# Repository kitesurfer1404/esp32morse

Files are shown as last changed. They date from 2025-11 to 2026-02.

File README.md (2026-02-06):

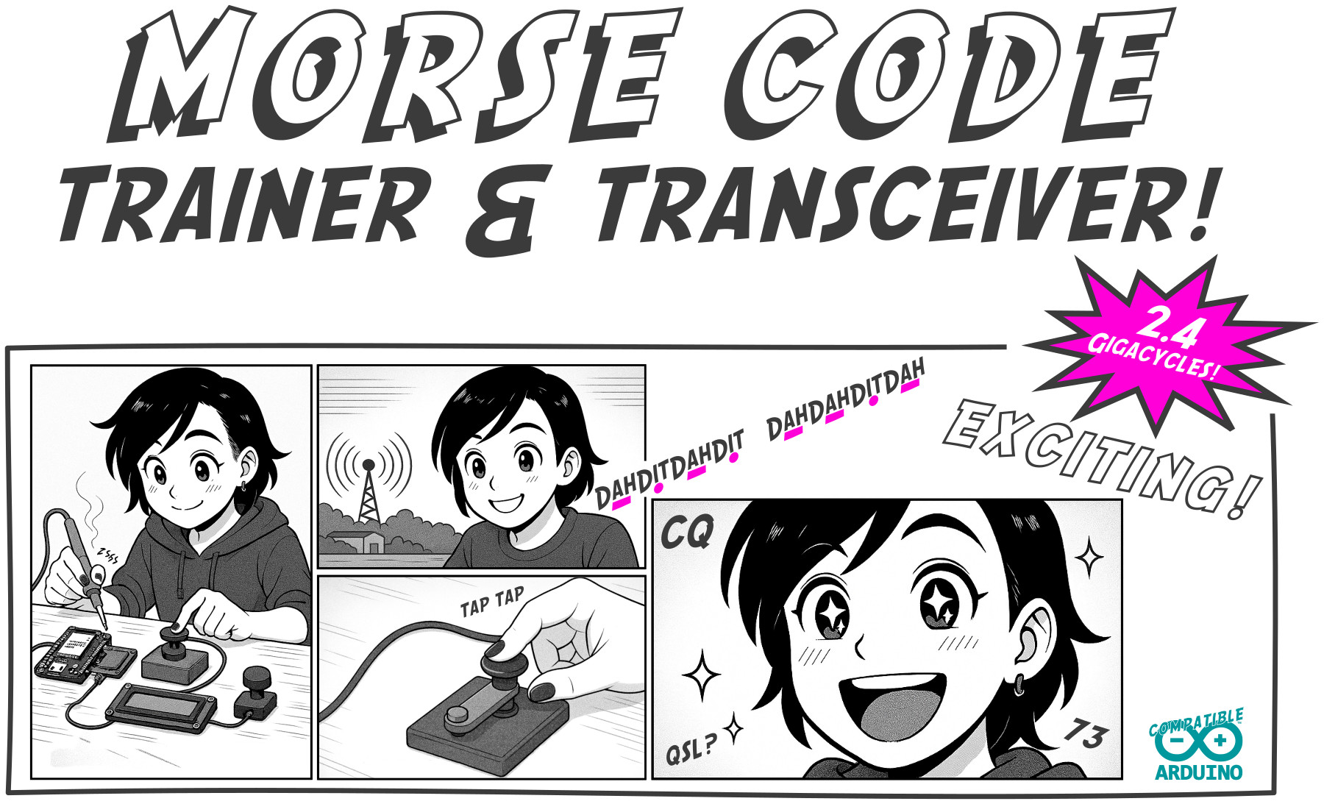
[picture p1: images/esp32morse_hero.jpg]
ESP32Morse Hero


ESP32Morse - Morse Toy and Trainer
==================================

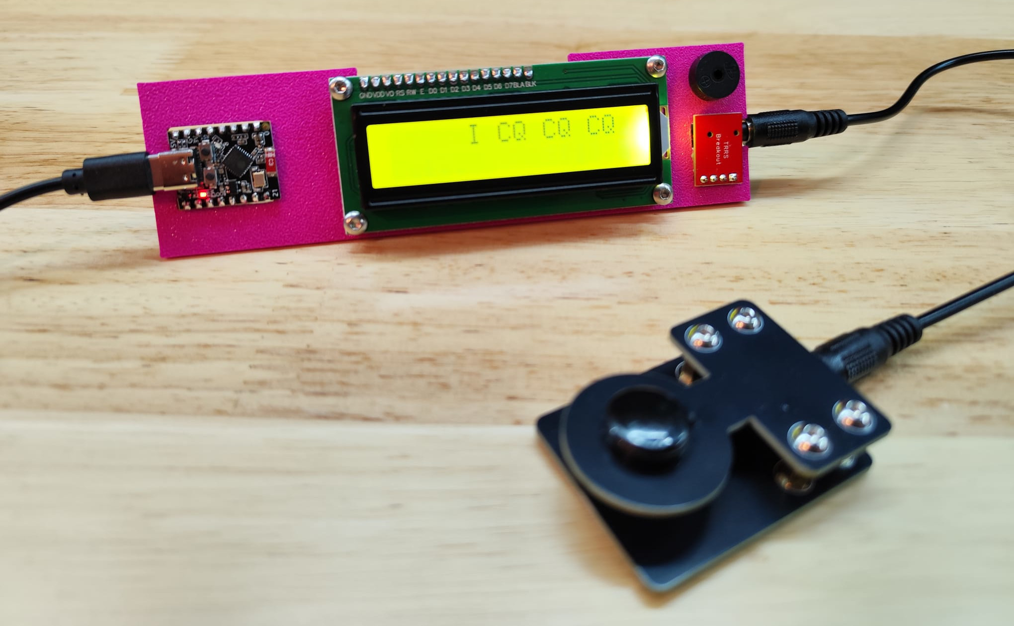
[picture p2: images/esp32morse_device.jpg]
ESP32Morse Device


This is a simple example of a CW decoder and trainer. The basic example code
sends out the characters over Wifi (ESPNow) to devices near you. 

The hardware is Morserino-compatible, the code is not (yet). Feel free to expand
the code to your needs and contribute to this repository!

You can use your own CW key or build a very basic one from any switch-ish 
device or material you can find. Go hacking! There is also a 
[PCB CW key](https://github.com/kitesurfer1404/pcb_cw_key) you can build.

BOM
---

* ESP32 C3 Super Mini w/ Pinheaders
* TRRS Breakout Board w/ Pinheaders
* 3V Piezo Speaker
* 2x16 Character LCD w/ I2C-interface
* Jumper Cables
* TRS-plug (optional)
* [3D printed Base Plate](baseplate) (optional)
* 4x M3x10 screws to mount the display (optional)
* Double Sided Tape (optional)

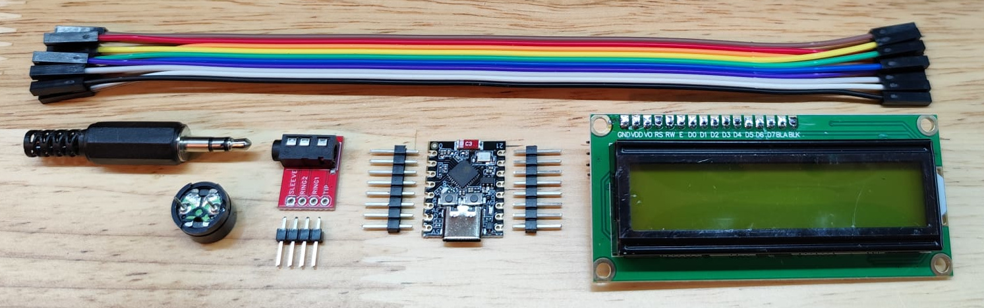
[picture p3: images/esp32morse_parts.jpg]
ESP32Morse Parts


Schematic
---------

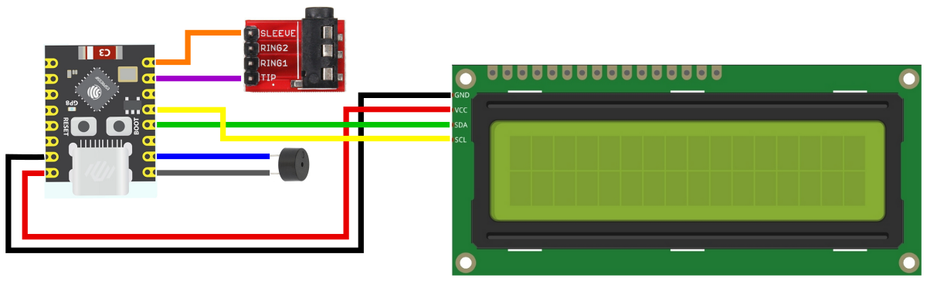
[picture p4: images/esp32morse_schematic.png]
ESP32Morse Schematic


Code
----

* [Very Basic Example](esp32morse/esp32morse.ino)

Build Instructions
------------------

Step 1: Solder the pinheaders.
* Solder pinheaders to the ESP32 board.
* Solder pinheaders to the TRRS breakout board.

Step 2: Wire everything.
**NOTE: The pins are labeled on the underside of the ESP32 board.**

* TRRS breakout: orange wire from sleeve to pin 21 of the ESP32 board.
* TRRS breakout: purple wire from tip to pin 20 of the ESP32 board.
* LCD: black wire from GND to GND of the ESP32 board.
* LCD: red wire from VCC to 5V of the ESP32 board.
* LCD: yellow wire from SCL to pin 9 of the ESP32 board.
* LCD: green wire from SDA to pin 8 of the ESP32 board.
* Speaker: blue wire from + to pin 6 of the ESP32 board.
* Speaker: gray wire from - to pin 5 of the ESP32 board.

Step 3: Programm ESP32.
* Use Arduino IDE.
* Follow instructions in the code.

Step 4: Adjust LCD contrast
* Power up ESP32 using a USB-C cable.
* Adjust LCD contrast by turning the potientiometer on the back of the LCD.

Step 5: Mount everything to the base plate (optional)
* Use double sided tape to stick ESP32 and TRRS to the baseplate.
* The speaker will friction fit.
* Screw LCD to the baseplate using 4x M3x10 screws.

Links to 3rd party morse keys
-----------------------------

* https://www.thingiverse.com/thing:7289028
* https://www.thingiverse.com/thing:6569884

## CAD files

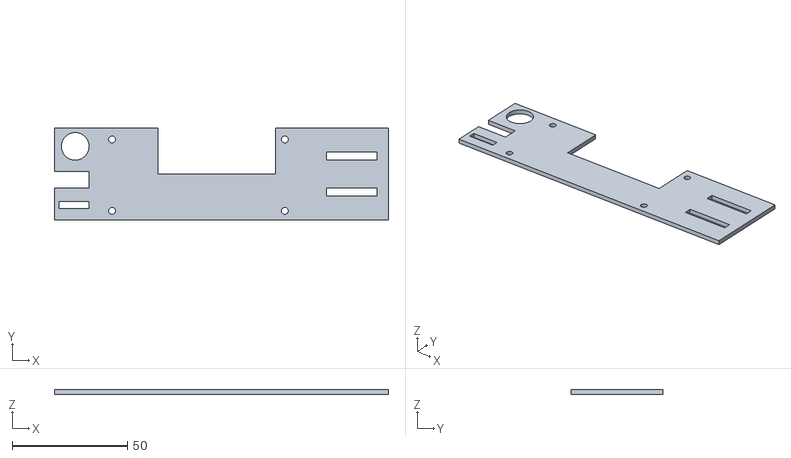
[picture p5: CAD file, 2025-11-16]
baseplate/ESP32-Morse-Plate.stl
145.0 x 40.0 x 2.00

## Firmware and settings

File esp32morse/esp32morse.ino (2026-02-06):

/*

Very basic Morse Code decoder and transceiver based on ESP32 C3 Super Mini.

--

The MIT License (MIT)

Copyright (c) 2025 DK4HAA

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
--

INSTALL

Install ESP32 via boards manager (if not done before)
  1. Open Arduino IDE
  2. Open Tools > Board > Boards Manager
  3. Search for "esp32"
  4. Install "esp32" by Espressif Systems

Install LiquidCrystal I2C library
  1. Select the library manager on the right
  2. Search for "LiquidCrystal I2C"
  3. Install the "LiquidCrystal I2C" library by Frank de Brabander

Select Board
  1. Select Tools > Board > esp32 > Nologo ESP32C3 Super Mini
  2. Use default settings for this board

Compile and install as usual. :)

*/

#include "esp_now.h"
#include "WiFi.h"

#include <Wire.h>
#include <LiquidCrystal_I2C.h>
LiquidCrystal_I2C lcd(0x27, 16, 2);

#define BUTTON_PIN 21
#define BUTTON_PIN_ARTIFICIAL_GND 20
#define TONE_PIN 6
#define TONE_PIN_ARTIFICIAL_GND 5

#define TONE_HZ 880
#define DOT_LENGTH_MS 120

#define ASCII_START 0x2E

unsigned long start_t, end_t;
String symbolBuffer = "";
String decodedText = "                ";
String rxText = "                ";

uint8_t broadcastAddress[] = { 0xFF, 0xFF, 0xFF, 0xFF, 0xFF, 0xFF };  //All stations broadcast address

// Structure to send/receive data
typedef struct struct_message {
  char msg[32];
  int ttl; // future use
  int tone_ms; // future use
} struct_message;

// Create a struct_message for rx and tx data
struct_message rxData;
struct_message txData;

esp_now_peer_info_t peerInfo;

static char cw_letters[][7] = {".-.-.-", "-..-.",                      // ./
                              "-----", ".----", "..---", "...--",      // 0123
                              "....-", ".....", "-....", "--...",      // 4567
                              "---..", "----.", "---...", "-.-.-.",    // 89:;
                              "", "-...-", "",                         // <=>
                              "..--..", ".--.-.",                      // ?@
                              ".-", "-...", "-.-.", "-..", ".",        // ABCDE
                              "..-.", "--.", "....", "..", ".---",     // FGHIJ
                              "-.-", ".-..", "--", "-.", "---",        // KLMNO
                              ".--.", "--.-", ".-.", "...", "-",       // PQRST
                              "..-", "...-", ".--", "-..-",            // UVWX
                              "-.--", "--..", "E"                      // YZ
                             };

void setup() {
  Serial.begin(115200);

  lcd.init();
  lcd.backlight();

  pinMode(BUTTON_PIN, INPUT_PULLUP);
  pinMode(BUTTON_PIN_ARTIFICIAL_GND, OUTPUT);

  pinMode(TONE_PIN, OUTPUT);
  pinMode(TONE_PIN_ARTIFICIAL_GND, OUTPUT);

  Serial.println(F("ESP32 Morse Toy"));
  Serial.println(F("by DK4HAA"));

  lcd.setCursor(0, 0);
  lcd.print("ESP32 Morse Toy");
  lcd.setCursor(0, 1);
  lcd.print("by DK4HAA");

  WiFi.mode(WIFI_STA);

  WiFi.setTxPower(WIFI_POWER_19_5dBm);
  
  // Init ESP-NOW
  if (esp_now_init() != ESP_OK) {
    Serial.println("Error initializing ESP-NOW");
    return;
  }

  // on data receive function
  esp_now_register_recv_cb(OnDataRecv);

  // on data send function
  esp_now_register_send_cb(OnDataSent);

  // Register peer
  memcpy(peerInfo.peer_addr, broadcastAddress, 6);
  peerInfo.channel = 0;
  peerInfo.encrypt = false;

  // Add peer
  if(esp_now_add_peer(&peerInfo) != ESP_OK) {
    Serial.println("Failed to add peer");
    return;
  }

  delay(2000);

  digitalWrite(BUTTON_PIN_ARTIFICIAL_GND, LOW);
  digitalWrite(TONE_PIN_ARTIFICIAL_GND, LOW);

  lcd.clear();

  updateDisplay();
}


void loop() {

  while(!morseKeyPressed()) { }     // wait until morse key is pressed
  tone(TONE_PIN, TONE_HZ);         // start tone
  start_t = millis();              // get start time
  while(morseKeyPressed()) { }      // wait until morse key is released
  noTone(TONE_PIN);                // turn off tone
  end_t = millis();                // get end time

  unsigned long duration = end_t - start_t;

  delay(50);
  if(duration < 20) {
    return;
  }

  char morseChar = charFromSignalDuration(duration);
  symbolBuffer += morseChar;

  // Wait to see if we're continuing on the same character (symbol buffer)
  while((millis() - end_t) < DOT_LENGTH_MS * 3) {
    if(morseKeyPressed()) {
      return;
    }
  }

  // Convert char
  int index = morseToCharacterIndex(symbolBuffer);

  symbolBuffer = "";

  if(index < 0) {
    return;
  }

  processChar(ASCII_START + index);

  // Wait to see if we're continuing on the same word
  // If we fall out of this loop, we'll append a space
  while((millis() - end_t) < DOT_LENGTH_MS * 7) {
    if(morseKeyPressed()) {
      return;
    }
  }

  // no char decoded for some time = send space
  processChar(32);
}

// callback when data is sent by ESPnow
void OnDataSent(const wifi_tx_info_t *tx_info, esp_now_send_status_t status) {
  //Serial.print("\r\nLast Packet Send Status:\t");
  //Serial.println(status == ESP_NOW_SEND_SUCCESS ? "Delivery Success" : "Delivery Fail");
}

// callback function that will be executed when data is received by ESPnow
void OnDataRecv(const esp_now_recv_info_t *esp_now_info, const uint8_t *incomingData, int len) {
  memcpy(&rxData, incomingData, sizeof(rxData));

  Serial.print("RX MSG: ");
  Serial.println(rxData.msg);

  // add received text to the display text and shift left
  rxText = rxText + rxData.msg;
  rxText.remove(0, strlen(rxData.msg));

  int i = characterToMorseIndex(rxData.msg[0]);
  if(i > 0) {
    Serial.print("CW: ");
    Serial.println(cw_letters[i]);

    morseToTone(cw_letters[i]);
  }

  // update display
  updateDisplay();
}

void updateDisplay() {
  lcd.setCursor(0, 0);
  lcd.print(decodedText);
  lcd.setCursor(0, 1);
  lcd.print(rxText);
}

void processChar(uint8_t code) {
  Serial.print("TX MSG: ");
  Serial.println(code, byte());
 
  txData.msg[0] = code;
  txData.ttl = 0;      // future use
  txData.tone_ms = 0;  // future use
  
  // Send message via ESPNow
  esp_err_t result = esp_now_send(broadcastAddress, (uint8_t *) &txData, sizeof(txData));
   
  // some debugging
  /*if(result == ESP_OK) {
    Serial.println("Sent with success");
  } else {
    Serial.println("Error sending the data");
  }*/

  decodedText = String(decodedText + char(code));
  decodedText.remove(0, 1);
  updateDisplay();
}

int morseToCharacterIndex(const String& morse) {
  int i = 0;
  while(String(cw_letters[i]) != "E") {
    if(String(cw_letters[i]) == morse) {
      return i;
    }
    i++;
  }
  return -1;
}

int characterToMorseIndex(const char c) {
  int i = (int)c - ASCII_START;
  return (i >= 0 && i < sizeof(cw_letters)/sizeof(cw_letters[0])) ? i : -1;
}

char charFromSignalDuration(unsigned long duration) {
  return (duration < DOT_LENGTH_MS * 1.5) ? '.' : '-';
}

bool morseKeyPressed() {
  return digitalRead(BUTTON_PIN) == LOW;
}

void morseToTone(const char* cw) {
  int i = 0;

  for(i = 0; i < strlen(cw); i++) {
    char c = cw[i];

    tone(TONE_PIN, TONE_HZ);

    if(c == '.') {
      delay(DOT_LENGTH_MS);
    } else {
      delay(DOT_LENGTH_MS * 3);
    }

    noTone(TONE_PIN);
    delay(DOT_LENGTH_MS);
  }
}

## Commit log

2025-11-16 3D printable baseplate added.
    [ESP32-Morse-Plate.stl]
2025-11-16 Schematic added, wire colors unified
